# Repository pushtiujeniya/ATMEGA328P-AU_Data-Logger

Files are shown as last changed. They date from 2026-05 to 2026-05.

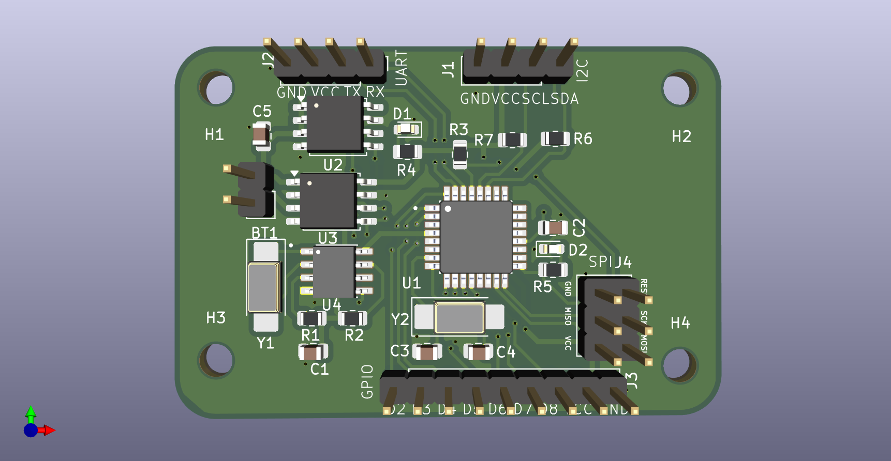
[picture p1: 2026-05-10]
3D view/3D_Top view.png

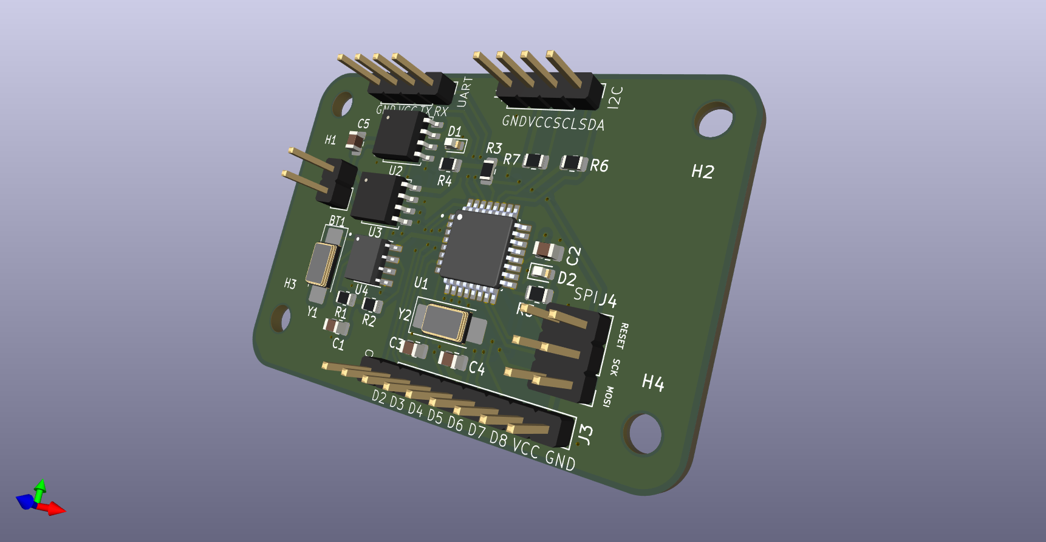
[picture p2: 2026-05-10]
3D view/3D_Side view.png

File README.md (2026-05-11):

# MCU Data Logger — ATmega328P + RTC + External dual EEPROM

# Features

- ATmega328P-AU AVR Microcontroller
- Dual 24LC1025 External EEPROMs
- DS1337S RTC (Real Time Clock)
- I2C Communication Bus
- UART Header
- SPI Programming Header
- External Crystal Oscillator
- Battery Powered Design
- Compact 2-Layer PCB
- GPIO Breakout Header
- RTC Backup Support

# Hardware Overview

## 1. Microcontroller

### ATmega328P-AU
Main controller used for:
- Data processing
- lower power consumption
- EEPROM communication
- RTC communication
- GPIO handling
- UART communication

### MCU Clock
- 16 MHz Crystal Oscillator
- Two 22 pF load capacitors

### Reset Circuit
- 10k pull-up resistor on RESET pin to keep the reset pin high in normal mode

### Power Decoupling
- 0.1uF decoupling capacitor near VCC  for power stabliity 

# Memory Storage

## External EEPROM

Two external EEPROM ICs are used:

- 24LC1025
- 24LC1025

### Communication
- I2C Protocol

### EEPROM Features
- Non-volatile memory
- Long-term data retention
- Byte and page write support

### Address Configuration

#### EEPROM U2
- A0 = VCC
- A1 = VCC
- A2 = VCC

#### EEPROM U3
- A0 = GND
- A1 = VCC
- A2 = VCC

This allows both EEPROMs to operate on the same I2C bus with different addresses.

### I2C Pull-up Resistors
- SDA → 4.7kΩ pull-up
- SCL → 4.7kΩ pull-up

# RTC Section
## DS1337S Real-Time Clock

Used for:
- Timekeeping
- Timestamp generation
- Scheduled logging
- supports battery backup oscillator

### RTC Crystal
- 32.768 kHz crystal oscillator

### RTC Interrupt
INT/SQW output available for:
- Alarm interrupt
- Periodic wakeup
---
# Communication Interfaces

## I2C Header
Exposed pins:
- SDA
- SCL
- VCC
- GND
  
Used for:
- External sensor connection
- Additional peripherals
  
## UART Header
Exposed pins:
- RX
- TX
- VCC
- GND
Used for:
- Serial debugging
- PC communication
- Data extraction
  
## SPI Header
6-pin SPI programming interface:
- MOSI
- MISO
- SCK
- RESET
- VCC
- GND

Used for:
- Bootloader flashing
- Firmware upload
  
# GPIO Header

Digital GPIO breakout:
- D2
- D3
- D4
- D5
- D6
- D7
- D8
- VCC
- GND

Used for:
- Sensor interfacing
- Digital peripherals
- Expansion

# Power System

## Input Power
Battery-powered design.

### Power Indicator
LED with 330Ω current-limiting resistor.

### Decoupling Capacitors
Used near IC power pins for:
- Noise reduction
- Stable operation

---

# PCB Design

## PCB Specifications

- 2-Layer PCB
- Through-hole + SMD mixed design
- Compact embedded layout
- NPTH Mounting holes provided for pcb support
  
### Design Considerations

- Separate signal routing
- Short I2C traces
- Pull-up resistors near bus
- Ground return optimization
- Crystal traces kept short

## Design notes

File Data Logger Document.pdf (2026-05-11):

ATMEGA328P-AU

- core : 8 bit AVR risc architecture
- Clock speed: up to 20 MHz
- operating voltage: 1.8v to 5.5v
- Package type: TQFP-32 smd
- Maximum current per pin:40 mA
- Total pins: 32 pin

The P stands for power efficient it is lower power consumption MCU

Pinout

Power pins: vcc , gnd, AVCC, AREF

GPIO pins:
23 programmable I/O pins
Each pin has internal pull up resistor PD0,PD1: UART (RX,TX)
PB3-PB5:SPI
PC4-PC5:I2C(SDA, SCL)
PC0-PC5: ADC input
PB6-PB7: crystal oscillator

Clock system

Internal RC oscillator: 8 MHz
External crystal oscillator: 16MHz with load capacitor

Current consumption

MCU: with 5v at 16MHz external crystal the current
Consumption by MCU = 10 to 20 mA( even when nothing is connected)

Total current consumption= MCU’s own current consumption + each external load current External components do not increase MCU internal current consumption but they draw current through MCU pins so total current consumption in circuit increases

24LC1025 memory

It is EEPROM( electrically erasable programmable read only memory) Nonvolatile ( store the data even after power off)
Total memory:512 K

Pinout
A0, A1, A2 - address select GND= ground
SDA= I2C data line
SCL= I2C clock line
WP= write protect
VCC= power
- The chip can be connect via I2C
- Each chip is 128KB EEPROM
- Two chip is 256KB total storage
- Operating voltage: 2.5V to 5.5V
- A0, A1, A2: address bits
- vcc= 3.3V
- GND= ground
- SDA , SCL = connect to MCU SDA , SCL via 4.7kohm pull up resistor
- WP= write protect
- If wp= connect with vcc( high) = write disabled and memory is read only
- If wp=connect with gnd (low) = write enabled and memory is readable and writeable
- No pull up resistor required for wp pin , can directly connect with vcc and gnd

A0 , A1, A2 : address pins

- Used to assign different address value when more than one i2c slave and master are connected with same i2c bus line
- Here A0 , A1, A2= connected with vcc = 0x57
- Other A0 , A2= Vcc and A1= gnd = 0x55
- Both memory has different address so master can communicate with particular one by assigning it’s specific address to the slave
- Here 2^3= 8 total combination of address range

MCU ATMEGA328P-AU connection

- Pin 3,21,5 = gnd pins = connected to ground
- Pin 4,6 =digital vcc
- Pin 16=AVCC= analog power supply voltage ( here in this board both are getting same voltage)
- Battery: through this the whole board will get the power supply
- Power on LED : indication for vcc line to show that board is power on or not
- PB6 and PB7: external crystal connection pins , 16MHz external crystal with load capacitors 22 PF
- Reset: PC6 pin is for reset , connect it with vcc through 10Kohm resistor to keep reset pin high in normal mode
- When MCU goes to reset the MCU pin goes to low

- Don’t keep this reset pin floating otherwise MCU may get randomly reset and power on
- AREF Pin: this pin is used to give stable analog reference voltage
- By this pin the ADC reading will not give wrong value if noise occur
- Keep 0.1 uF capacitor connect with AREF pin to gnd for decoupling
- UART pins: PD0= RX, PD1= TX
- Used for programming and debugging
- SPI interface:
- PB3= MOSI
- PB4=MISO
- PB5=SCK
- I2C interface
- PC4=SDA, PC5 =SCL
- GPIO pins
- PB0-PB5, PD2- PD7, PC0 - PC3

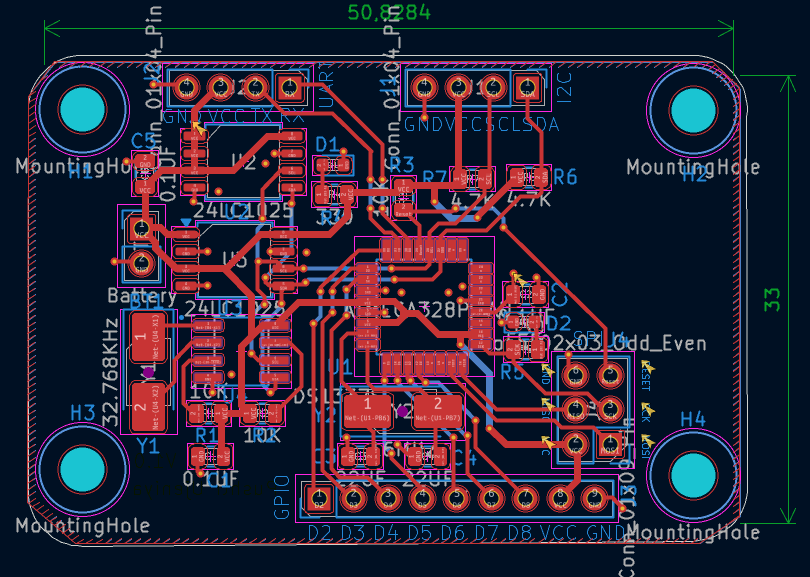
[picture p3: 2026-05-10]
layout image.png

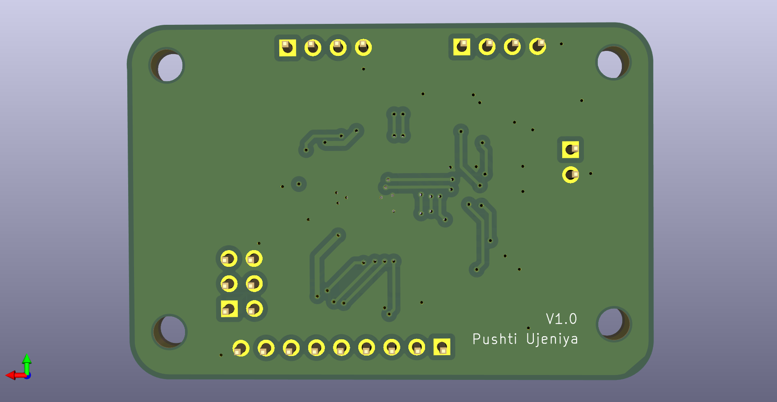
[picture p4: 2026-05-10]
3D view/3D_Bottom view.png

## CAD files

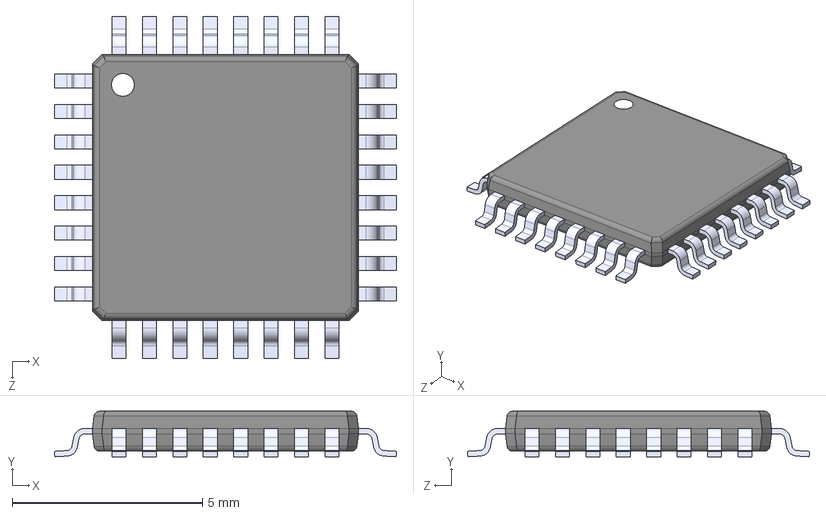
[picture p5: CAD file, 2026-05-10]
External Library/ATMEGA328P-AU/ATMEGA328P-AU.step
9.00 x 1.20 x 9.00 mm

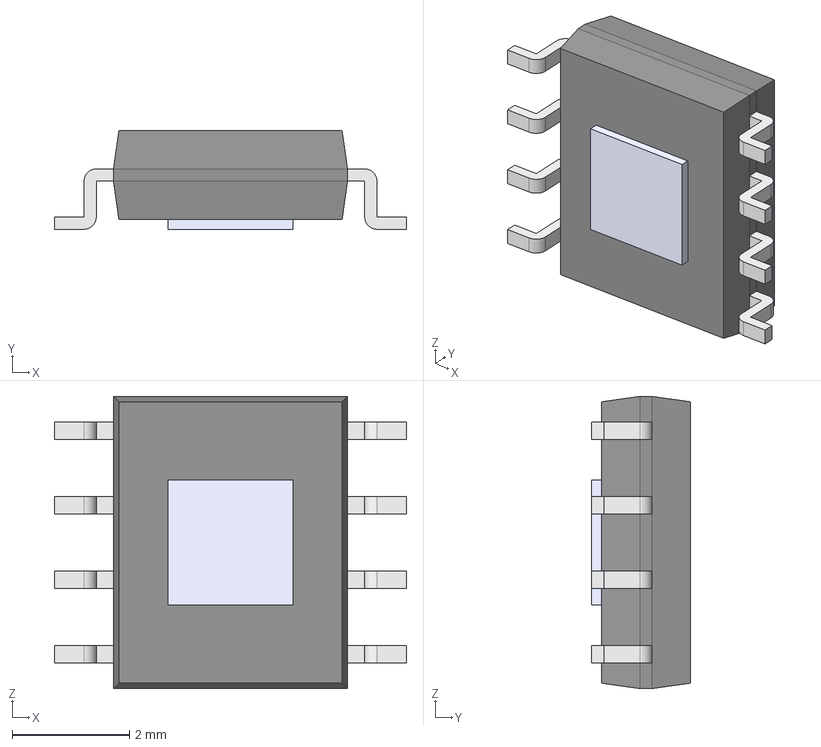
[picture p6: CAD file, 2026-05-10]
External Library/DS1337S+/DS1337S+.step
6.00 x 1.68 x 4.98 mm
Body001 (Mirror #1) x 4
XY-plane x 12
X-axis x 12

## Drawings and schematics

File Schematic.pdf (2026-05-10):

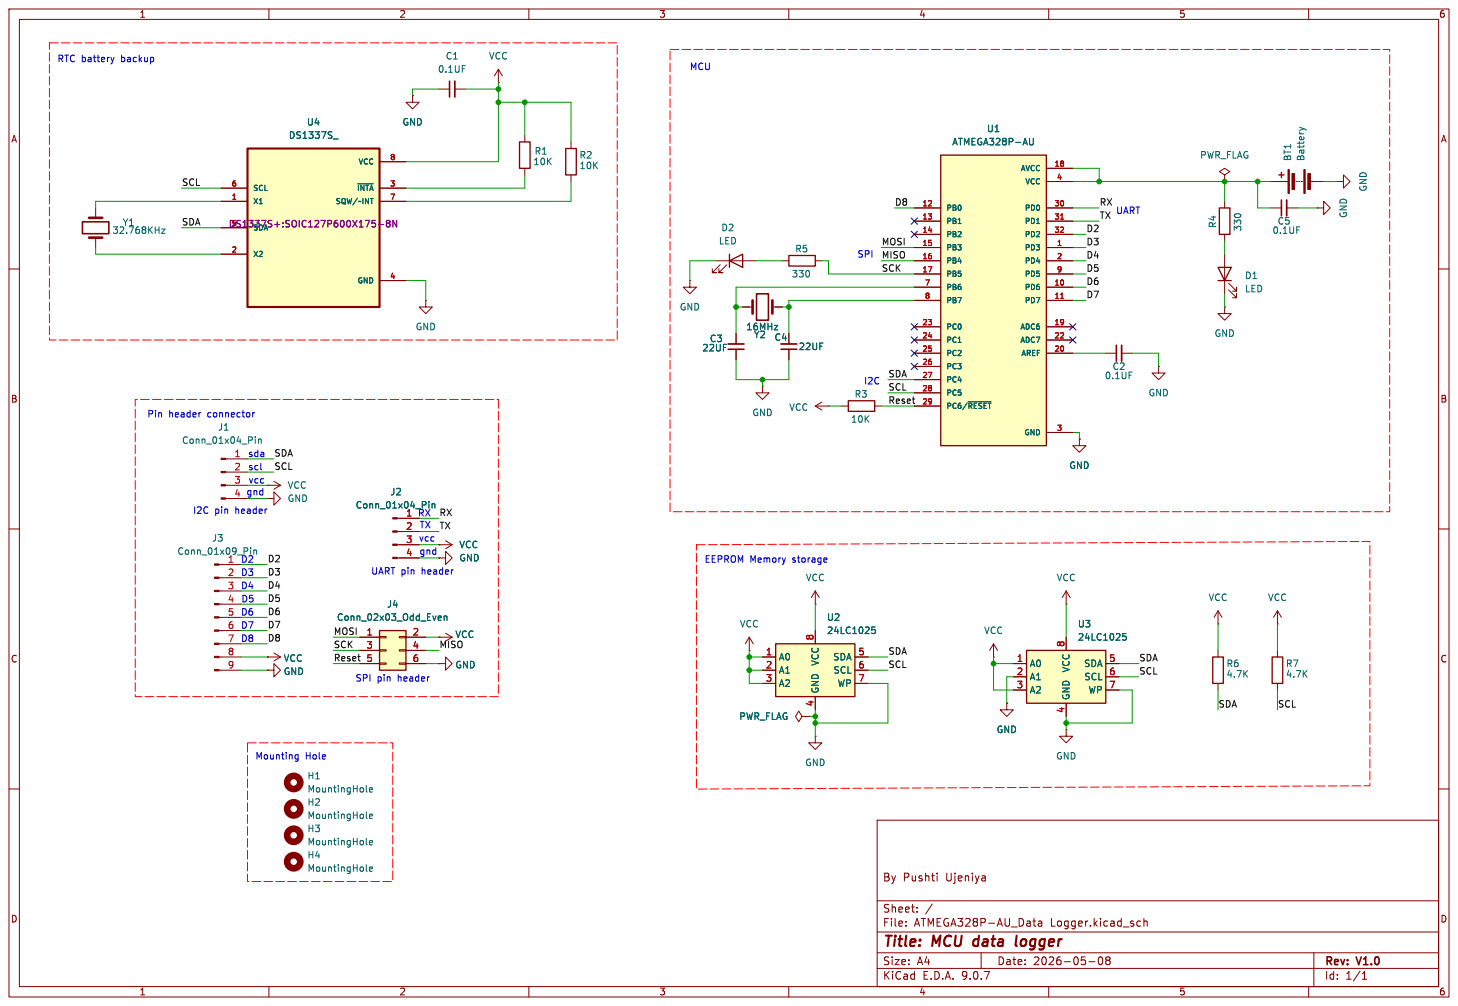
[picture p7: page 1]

VCC GND GND GND

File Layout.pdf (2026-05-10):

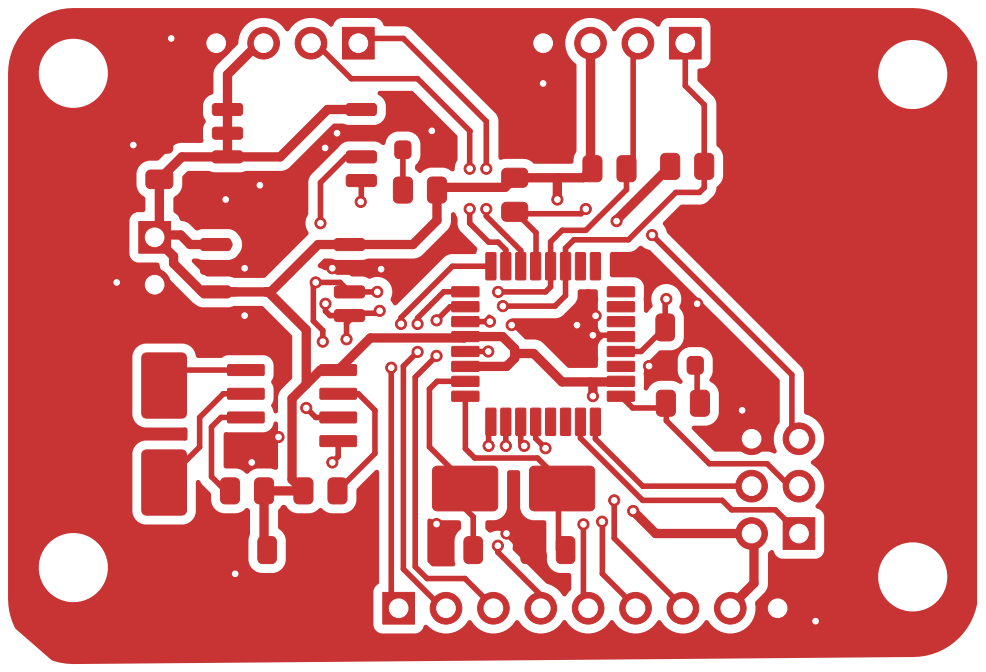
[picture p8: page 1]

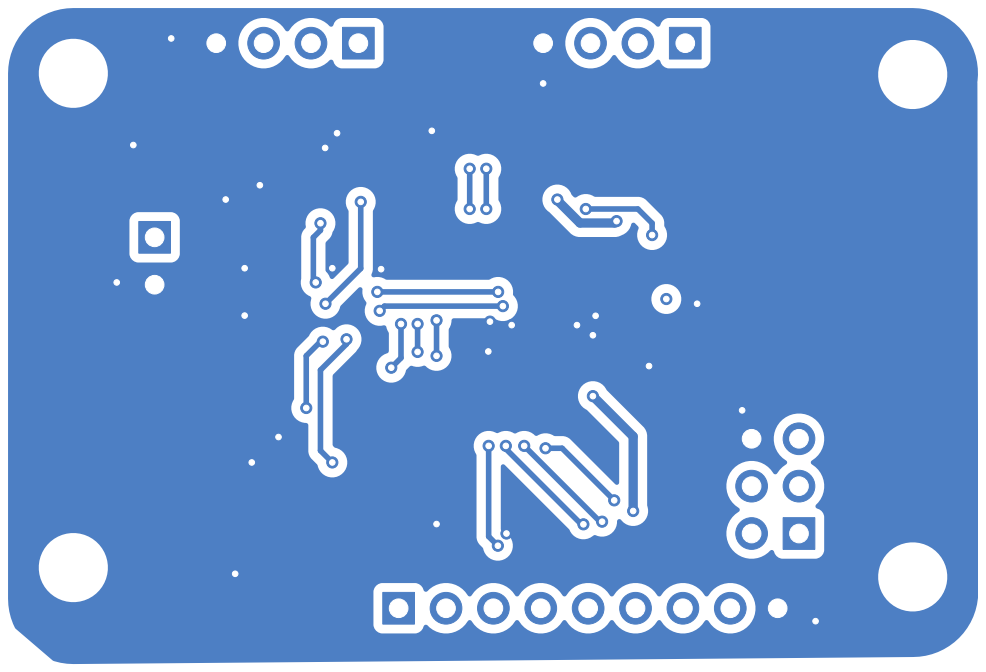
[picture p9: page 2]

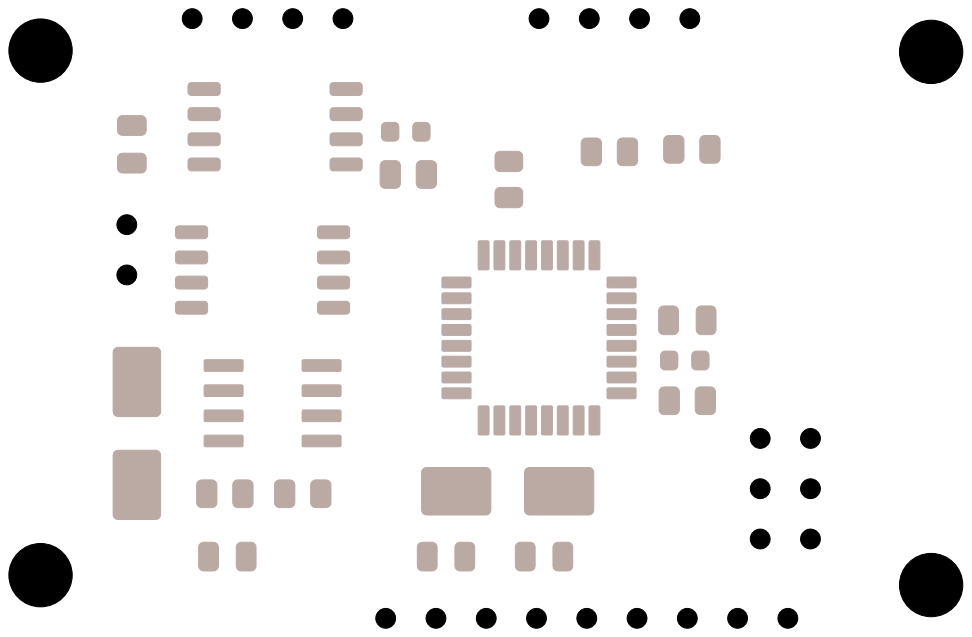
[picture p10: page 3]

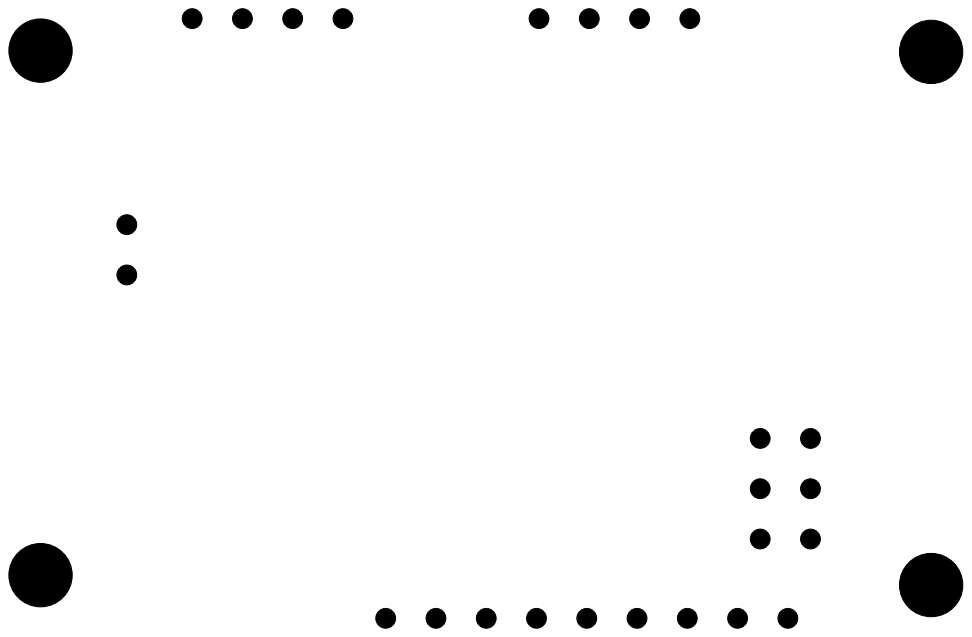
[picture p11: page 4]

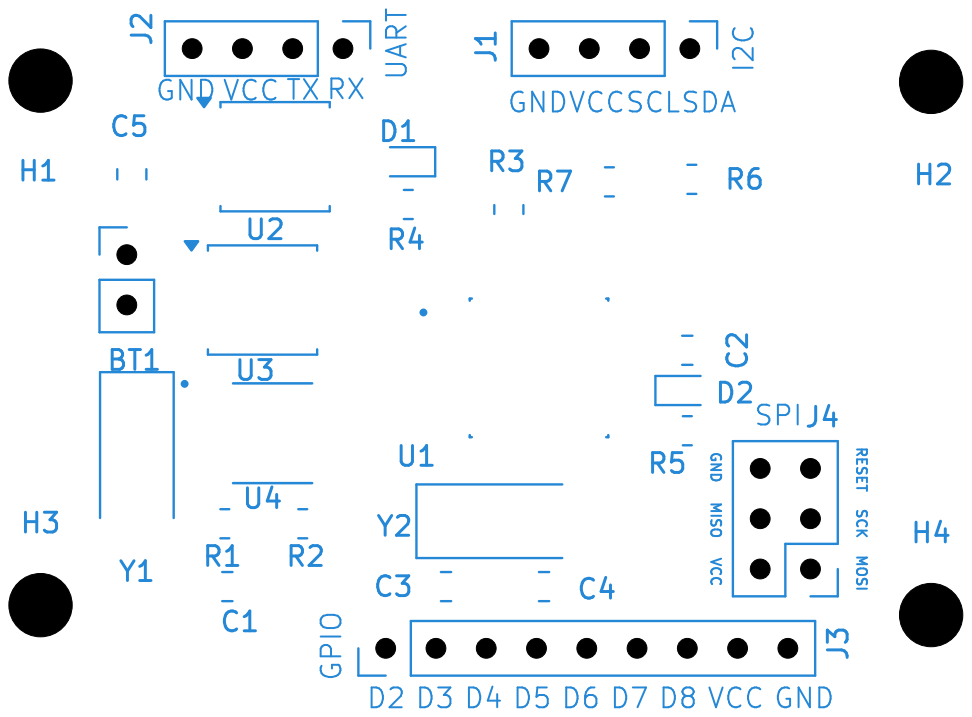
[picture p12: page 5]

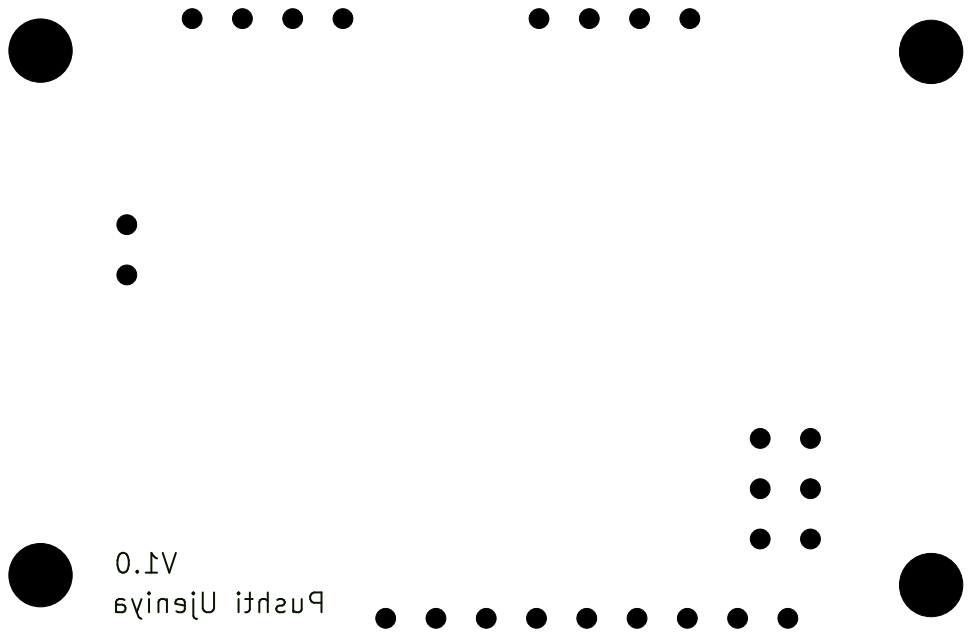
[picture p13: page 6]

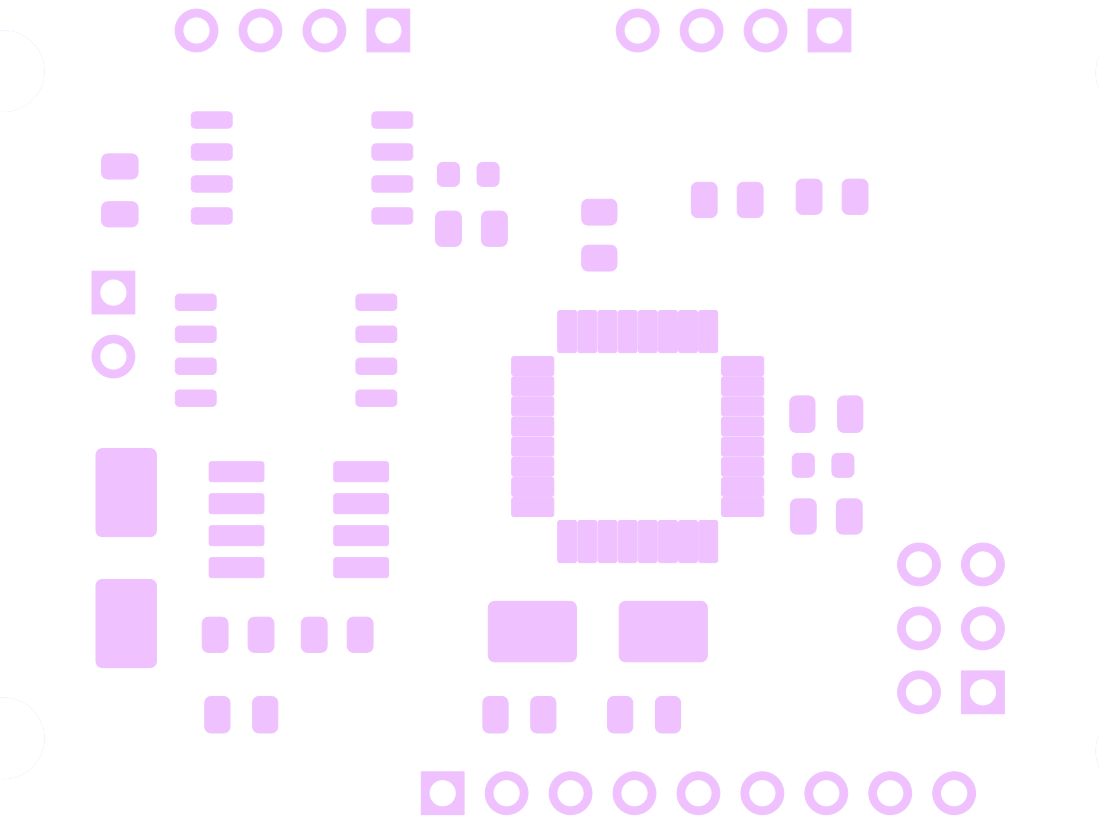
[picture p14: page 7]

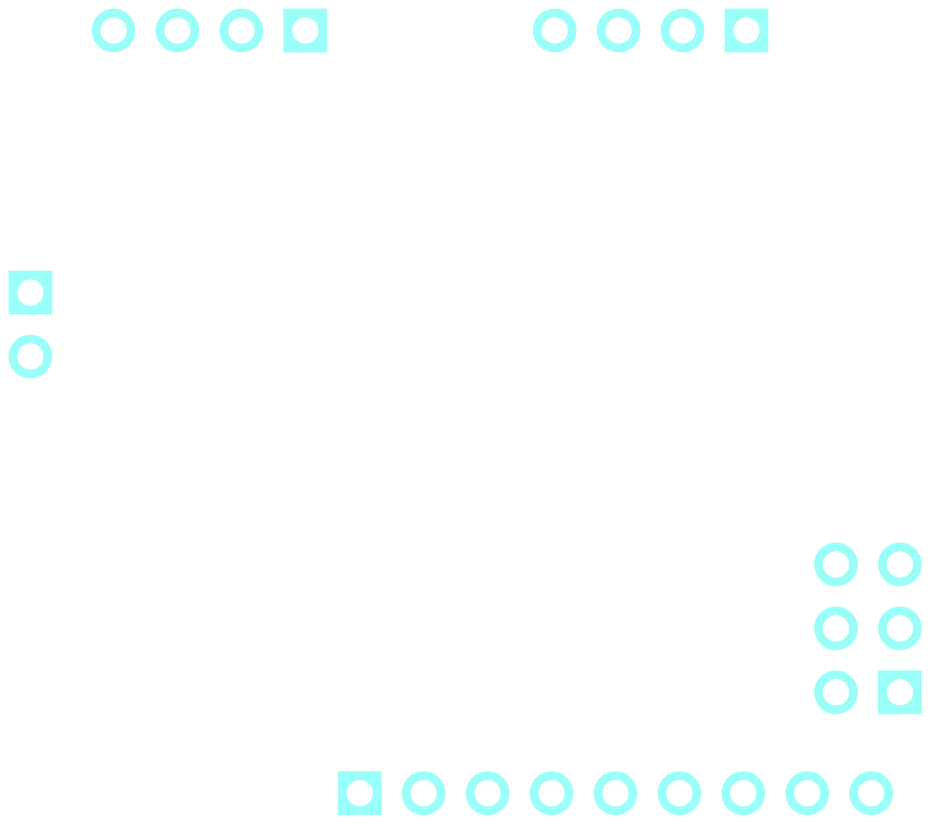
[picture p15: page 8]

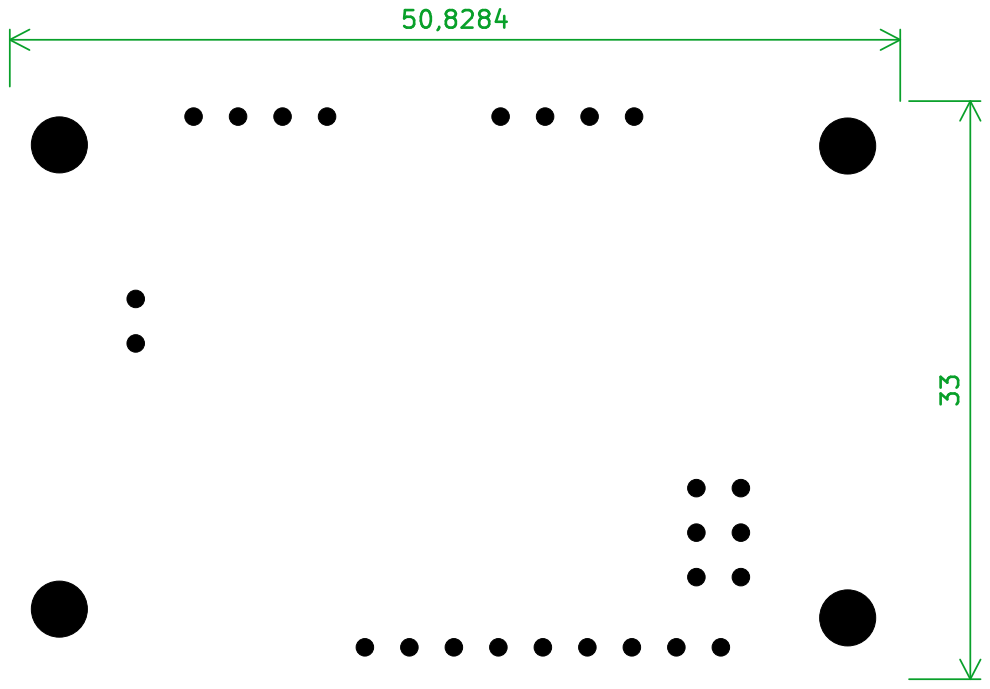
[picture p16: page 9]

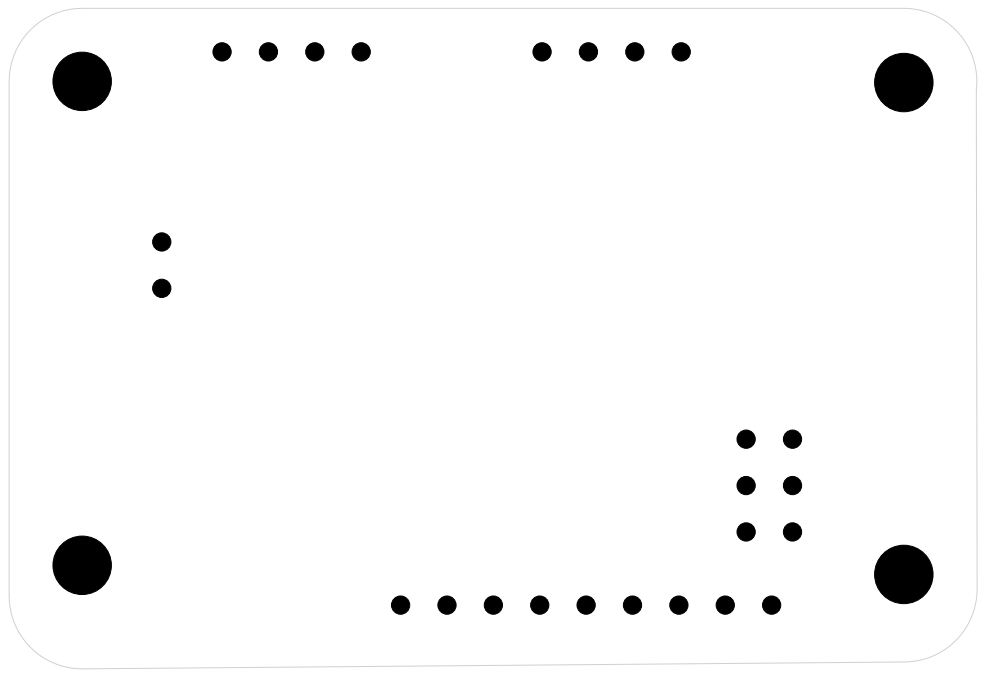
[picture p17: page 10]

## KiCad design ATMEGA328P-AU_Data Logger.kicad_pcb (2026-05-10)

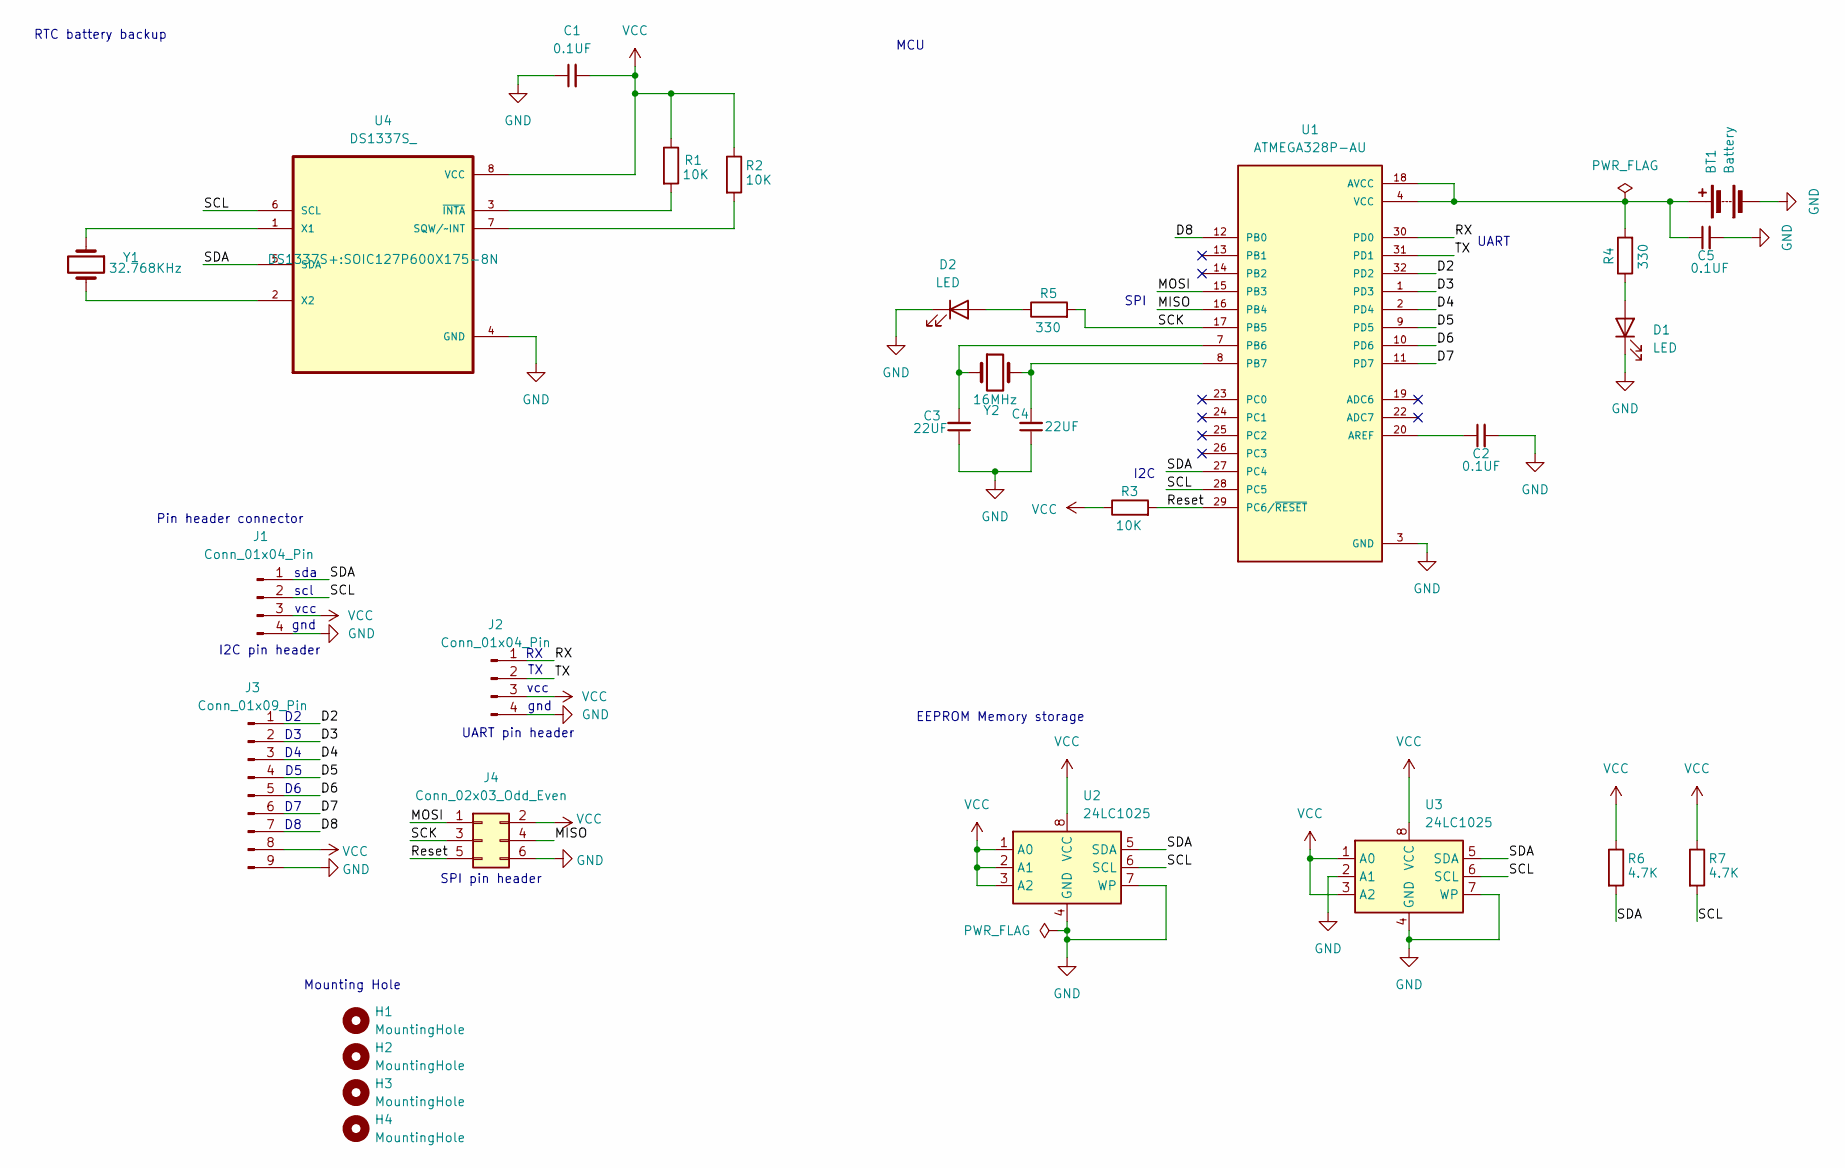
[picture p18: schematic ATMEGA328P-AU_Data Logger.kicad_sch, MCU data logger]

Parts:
BT1: Battery; PinHeader_1x02_P2.54mm_Vertical
C1, C2, C5: 0.1UF; C_0805_2012Metric
C3, C4: 22UF; C_0805_2012Metric
D1, D2: LED; LED_0603_1608Metric
H1, H2, H3, H4: MountingHole; MountingHole_3.2mm_M3
J1, J2: Conn_01x04_Pin; PinHeader_1x04_P2.54mm_Vertical
J3: Conn_01x09_Pin; PinHeader_1x09_P2.54mm_Vertical
J4: Conn_02x03_Odd_Even; PinHeader_2x03_P2.54mm_Vertical
R1, R2, R3: 10K; R_0805_2012Metric
R4, R5: 330; R_0805_2012Metric
R6, R7: 4.7K; R_0805_2012Metric
U1: ATMEGA328P-AU; QFP80P900X900X120-32N; PARTREV 8271A
U2, U3: 24LC1025; SOIC-8_5.3x5.3mm_P1.27mm
U4: DS1337S_; SOIC127P600X175-8N
Y1: 32.768KHz; Crystal_SMD_5032-2Pin_5.0x3.2mm_HandSoldering
Y2: 16MHz; Crystal_SMD_5032-2Pin_5.0x3.2mm_HandSoldering

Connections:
/D2: J3.1, U1.32 (PD2)
/D3: J3.2, U1.1 (PD3)
/D4: J3.3, U1.2 (PD4)
/D5: J3.4, U1.9 (PD5)
/D6: J3.5, U1.10 (PD6)
/D7: J3.6, U1.11 (PD7)
/D8: J3.7, U1.12 (PB0)
/MISO: J4.4, U1.16 (PB4)
/MOSI: J4.1, U1.15 (PB3)
/RX: J2.1, U1.30 (PD0)
/Reset: J4.5, R3.2, U1.29 (PC6/~RESET)
/SCK: J4.3, R5.2, U1.17 (PB5)
/SCL: J1.2, R7.2, U1.28 (PC5), U2.6 (SCL), U3.6 (SCL), U4.6 (SCL)
/SDA: J1.1, R6.2, U1.27 (PC4), U2.5 (SDA), U3.5 (SDA), U4.5 (SDA)
/TX: J2.2, U1.31 (PD1)
GND: BT1.2 (-), C1.1, C2.2, C3.1, C4.1, C5.2, D1.1 (K), D2.1 (K), J1.4, J2.4, J3.9, J4.6, U1.3 (GND), U1.5 (GND), U1.21 (GND), U2.4 (GND), U2.7 (WP), U3.2 (A1), U3.4 (GND), U3.7 (WP), U4.4 (GND)
unnamed: D1.2 (A), R4.1
unnamed: D2.2 (A), R5.1
unnamed: C2.1, U1.20 (AREF)
unnamed: C3.2, U1.7 (PB6), Y2.1
unnamed: C4.2, U1.8 (PB7), Y2.2
unnamed: R2.2, U4.7 (SQW/~INT)
unnamed: U4.1 (X1), Y1.1
unnamed: U4.2 (X2), Y1.2
unnamed: R1.2, U4.3 (~INTA)

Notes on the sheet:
UART
Pin header connector
I2C pin header
vcc
RTC battery backup
gnd
SPI
sda
Mounting Hole
MCU
I2C
UART pin header
SPI pin header
scl
EEPROM Memory storage

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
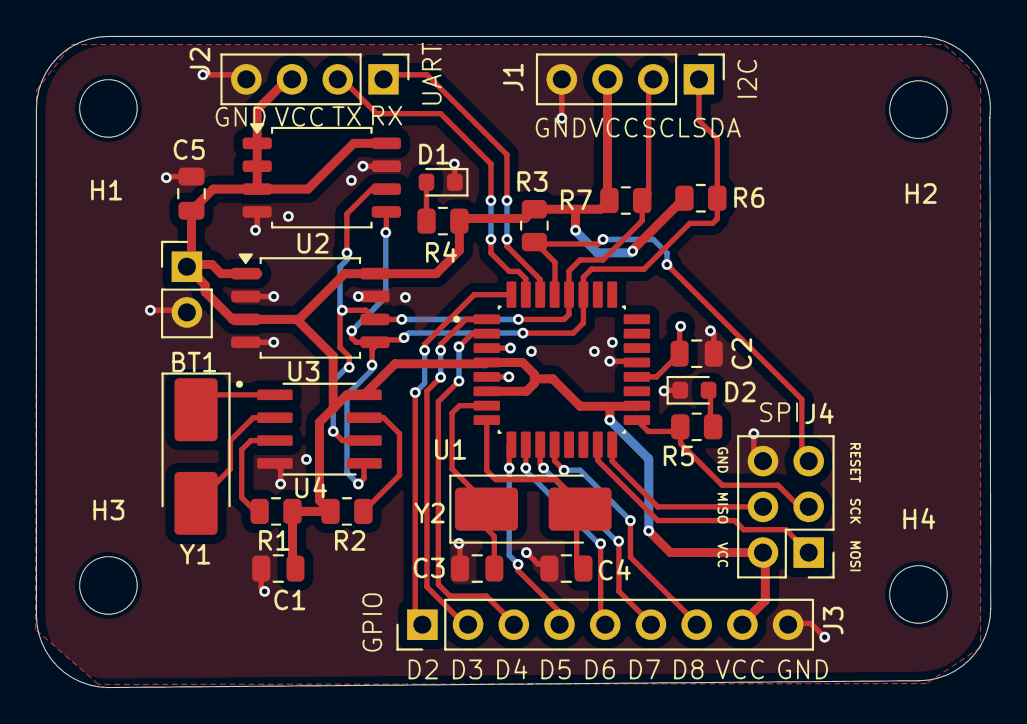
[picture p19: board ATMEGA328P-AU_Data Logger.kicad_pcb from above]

Board: 2 copper layers, 53.0 x 36.2 mm, 29 parts (0 on the bottom side), 26 nets.

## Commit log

2026-05-10 atmega328p-au symbol and step file added
    [ATMEGA328P-AU.step]
2026-05-10 atmega328p-au footprint file added
2026-05-10 symbol and step file added
    [DS1337S+.step]
2026-05-10 footprint file added
2026-05-10 schematic and layout file added
2026-05-10 schematic file added
    [ATMEGA328P-AU_Data Logger.kicad_sch]
2026-05-10 layout file added
    [ATMEGA328P-AU_Data Logger.kicad_pcb]
2026-05-11 Revise README with comprehensive project details
    Updated README to provide detailed project features, hardware overview, memory storage, communication interfaces, GPIO header, power system, and PCB design specifications.
